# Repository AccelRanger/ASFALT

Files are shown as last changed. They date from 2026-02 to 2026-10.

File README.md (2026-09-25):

# ASFALT
**Accel Systems Line Following Robot**

A high-resolution line follower or edge follower calibrated for both usecases (TRD < for edge following, normal for line following) built on an Arduino Nano (ATmega328P), featuring a 16-sensor U-shaped IR array, custom KiCad PCBs, 3D-printed chassis parts, and a PID/proportional control algorithm with priority-based corner handling.

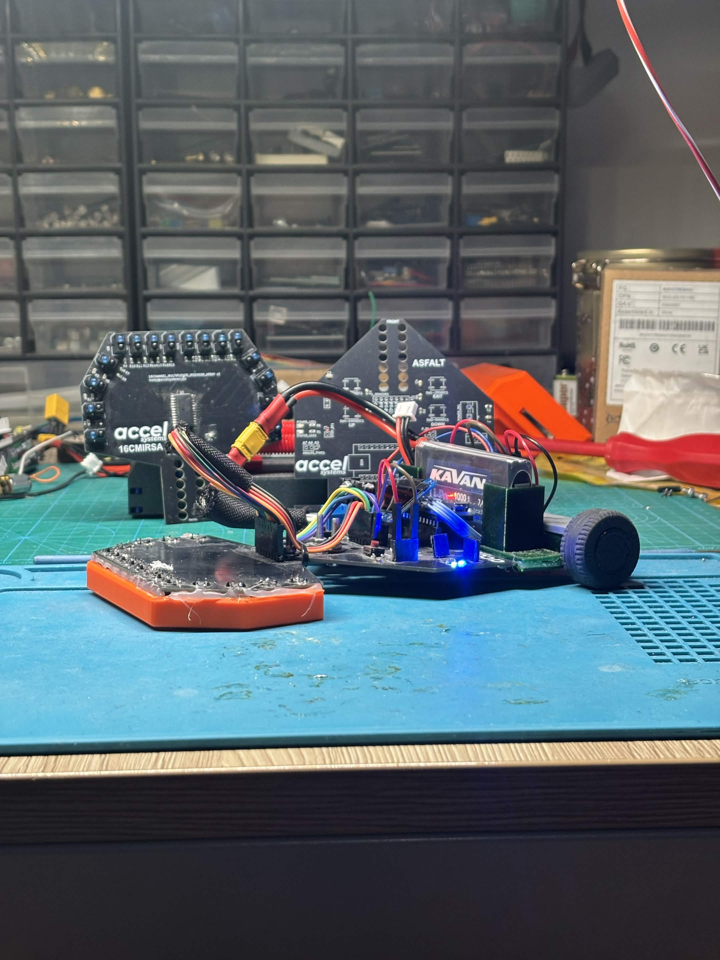
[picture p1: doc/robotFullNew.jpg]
Robot view Robot View


## License

This project is open source. Hardware designs, firmware, and mechanical files are provided as-is for personal and educational use.

---

*ASFALT — Accel Systems Line Following Robot*
*ASFALT-REV2 > Updated version single PCB, This repo has support till 1/10/2026

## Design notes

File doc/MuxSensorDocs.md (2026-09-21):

# MuxSensor

Custom Library for reading sensor inputs from 16CMIRSA

---

## Table of contents

- [Overview](#overview)
- [Constants](#constants)
- [Enums](#enums)
- [Constructor](#constructor)
- [API reference](#api-reference)
- [Calibration details](#calibration-details)
- [Digital thresholding](#digital-thresholding)
- [Channel select table](#channel-select-table)
- [Example sketch](#example-sketch)
- [Debug snippet](#debug-snippet)
- [Notes and caveats](#notes-and-caveats)

---

## Overview

`MuxSensor` controls a 16-to-1 analog multiplexer using four digital select lines (S0–S3) and one analog input (COM). It reads each of the 16 channels in sequence, runs a live calibration pass to record each sensor's min/max ADC extremes, and converts raw 10-bit ADC values to digital 0/1 signals using per-channel hysteresis windows.

Designed for **line-following robots** where a bank of IR sensors (e.g. TCRT5000) feeds a single ADC pin through a mux.

---

## Constants

| Macro | Value | Description |
|---|---|---|
| `MUX_NUM_CHANNELS` | `16` | Total channels on the multiplexer. |
| `MUX_CALIB_MARGIN` | `30` | ±ADC counts around each calibrated extreme forming the hysteresis window. Reduces noise-induced toggling. |
| `MUX_SETTLE_US` | `200` | Microseconds to wait after switching the mux channel before sampling. Allows the analog signal to settle. |

---

## Enums

### `MuxPolarity`

Describes how the sensor's ADC output maps to surface colour.

| Value | Description |
|---|---|
| `POLARITY_DARK_LOW` | Black surface → low ADC reading. Typical for TCRT5000 and most reflective IR sensors. **Default.** |
| `POLARITY_DARK_HIGH` | Black surface → high ADC reading. Use when your sensor circuit is inverted. |

---

## Constructor

```cpp
MuxSensor(uint8_t pinS0, uint8_t pinS1, uint8_t pinS2, uint8_t pinS3,
          uint8_t pinCOM,
          MuxPolarity polarity = POLARITY_DARK_LOW);
```

Creates a `MuxSensor` instance. Does **not** configure any pins — call `begin()` after construction.

| Parameter | Type | Description |
|---|---|---|
| `pinS0`–`pinS3` | `uint8_t` | Digital output pins connected to the mux select lines S0, S1, S2, S3. |
| `pinCOM` | `uint8_t` | Analog input pin connected to the mux common output (Z pin). |
| `polarity` | `MuxPolarity` | Optional. Sensor polarity. Defaults to `POLARITY_DARK_LOW`. |

All calibration arrays are initialised to `_calMin = 0`, `_calMax = 1023`, and `_calibrated = false`.

---

## API reference

### `begin()`

```cpp
void begin();
```

Sets S0–S3 as `OUTPUT` and selects channel 0. Call once in `setup()`.

> **Note:** Does not call `pinMode` on the COM pin. Make sure the COM pin is not configured as a digital output elsewhere in your sketch.

---

### `calibrate()`

```cpp
bool calibrate(uint32_t durationMs = 12000UL);
```

Sweeps all 16 channels continuously for `durationMs` milliseconds, recording the minimum and maximum ADC value seen on each channel. Move the sensor array over both black and white surfaces during this window.

| Parameter | Type | Description |
|---|---|---|
| `durationMs` | `uint32_t` | Calibration window in milliseconds. Default `12000` ms. |

**Returns** `true` if every channel has sufficient contrast — i.e. `calMin[i] + MUX_CALIB_MARGIN < calMax[i] - MUX_CALIB_MARGIN`. Returns `false` if any channel's range is too narrow, but still sets `_calibrated = true` so subsequent reads can proceed.

> **Warning:** This call **blocks the main loop** for the full duration. Use a non-blocking state machine if that is a concern.

---

### `isCalibrated()`

```cpp
bool isCalibrated() const;
```

Returns `true` after a successful `calibrate()` call, regardless of whether contrast was adequate on all channels.

---

### `getRawAnalogValues()`

```cpp
void getRawAnalogValues(uint16_t out[MUX_NUM_CHANNELS]);
```

Reads all 16 channels in order (ch0 → ch15) and writes the raw 10-bit ADC value (0–1023) into `out`. Does not require prior calibration.

| Parameter | Type | Description |
|---|---|---|
| `out` | `uint16_t[16]` | Caller-allocated array of 16 elements. Filled in channel order. |

---

### `getDigital()`

```cpp
bool getDigital(uint8_t out[MUX_NUM_CHANNELS]);
```

Reads all channels, applies the calibrated hysteresis windows, and writes a digital `0` or `1` per channel into `out`.

| Parameter | Type | Description |
|---|---|---|
| `out` | `uint8_t[16]` | Caller-allocated array. Each element is `0` (white / no surface) or `1` (black / surface detected), depending on polarity. |

**Returns** `false` immediately — leaving `out` unchanged — if `_calibrated` is `false`. Returns `true` on success.

If the current reading falls outside both the black and white zones, the previous digital value for that channel is retained (`_lastDigital[ch]`). This prevents glitching in mid-transition regions.

---

### `getCalibMin()`

```cpp
uint16_t getCalibMin(uint8_t ch) const;
```

Returns the minimum ADC value recorded for channel `ch` during the last calibration. Returns `0` for out-of-range channel indices.

---

### `getCalibMax()`

```cpp
uint16_t getCalibMax(uint8_t ch) const;
```

Returns the maximum ADC value recorded for channel `ch` during the last calibration. Returns `0` for out-of-range channel indices.

---

### `getThreshold()`

```cpp
uint16_t getThreshold(uint8_t ch) const;
```

Returns the midpoint `(calMin[ch] + calMax[ch]) / 2` for channel `ch`. Useful as a simple fixed threshold for debugging. Returns `0` for out-of-range channel indices.

---

## Calibration details

During `calibrate()`, the library:

1. Resets `_calMin[i]` to `1023` and `_calMax[i]` to `0` for all channels.
2. Polls all 16 channels in a tight loop (with 1 ms delay per sweep) until the deadline is reached.
3. After the sweep, checks whether each channel has enough contrast: `_calMin[i] + MUX_CALIB_MARGIN < _calMax[i] - MUX_CALIB_MARGIN`.
4. Sets `_calibrated = true` unconditionally and returns the contrast check result.

For reliable calibration, ensure the sensor passes over a clear black surface **and** a clear white surface during the calibration window.

---

## Digital thresholding

`getDigital()` defines two zones per channel based on calibrated extremes and `MUX_CALIB_MARGIN`:

```
blackLo = calMin[ch] - MUX_CALIB_MARGIN   (clamped to 0)
blackHi = calMin[ch] + MUX_CALIB_MARGIN

whiteLo = calMax[ch] - MUX_CALIB_MARGIN   (clamped to 0)
whiteHi = calMax[ch] + MUX_CALIB_MARGIN
```

The mapping of zones to digital output depends on polarity:

| Zone | `POLARITY_DARK_LOW` output | `POLARITY_DARK_HIGH` output |
|---|---|---|
| Reading in black zone | `1` | `0` |
| Reading in white zone | `0` | `1` |
| Reading in neither zone | retain previous value | retain previous value |

---

## Channel select table

The CD74HC4067 select lines S3, S2, S1, S0 address channels 0–15 as follows:

| Channel | S3 | S2 | S1 | S0 |
|---|---|---|---|---|
| 0  | 0 | 0 | 0 | 0 |
| 1  | 0 | 0 | 0 | 1 |
| 2  | 0 | 0 | 1 | 0 |
| 3  | 0 | 0 | 1 | 1 |
| 4  | 0 | 1 | 0 | 0 |
| 5  | 0 | 1 | 0 | 1 |
| 6  | 0 | 1 | 1 | 0 |
| 7  | 0 | 1 | 1 | 1 |
| 8  | 1 | 0 | 0 | 0 |
| 9  | 1 | 0 | 0 | 1 |
| 10 | 1 | 0 | 1 | 0 |
| 11 | 1 | 0 | 1 | 1 |
| 12 | 1 | 1 | 0 | 0 |
| 13 | 1 | 1 | 0 | 1 |
| 14 | 1 | 1 | 1 | 0 |
| 15 | 1 | 1 | 1 | 1 |

---

## Example sketch

```cpp
#include "MuxSensor.h"

// S0=4, S1=5, S2=6, S3=7, COM=A0
MuxSensor mux(4, 5, 6, 7, A0, POLARITY_DARK_LOW);

void setup() {
  Serial.begin(115200);
  mux.begin();

  Serial.println("Calibrating — move over black and white...");
  bool ok = mux.calibrate(5000);  // 5-second window
  Serial.println(ok ? "Calibrated OK" : "Low contrast on some channels");
}

void loop() {
  uint8_t bits[MUX_NUM_CHANNELS];
  if (mux.getDigital(bits)) {
    for (uint8_t i = 0; i < MUX_NUM_CHANNELS; i++) {
      Serial.print(bits[i]);
    }
    Serial.println();
  }
  delay(20);
}
```

---

## Debug snippet

Print calibration data for every channel after `calibrate()`:

```cpp
for (uint8_t i = 0; i < MUX_NUM_CHANNELS; i++) {
  Serial.print("ch");    Serial.print(i);
  Serial.print("  min="); Serial.print(mux.getCalibMin(i));
  Serial.print("  max="); Serial.print(mux.getCalibMax(i));
  Serial.print("  thr="); Serial.println(mux.getThreshold(i));
}
```

---

## Notes and caveats

- `calibrate()` always sets `_calibrated = true` even when it returns `false` (poor contrast). Reads via `getDigital()` will proceed — results may be unreliable on affected channels.
- `getThreshold()` is declared in the header but may not be present in all versions of the `.cpp`. Verify it is implemented before use.
- `MUX_SETTLE_US` (200 µs) is conservative. On fast MCUs you may be able to reduce it if your mux and sensor settle faster, saving time during full sweeps.
- Total scan time per full `getDigital()` call is approximately `16 × (MUX_SETTLE_US + analogRead time)` — roughly 3–5 ms on a standard Arduino Uno at default ADC prescaler.

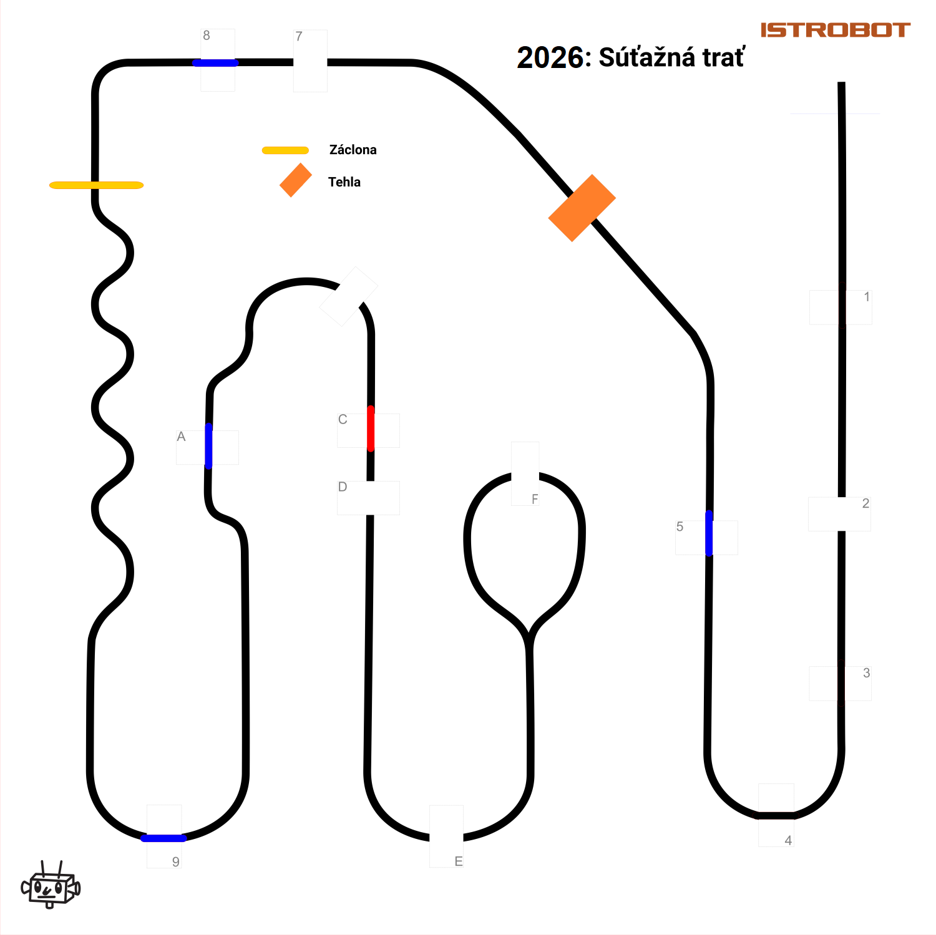
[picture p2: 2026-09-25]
src/img/LinefollowerTrack2026.png

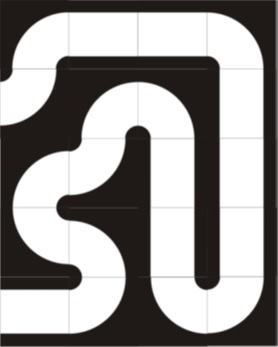
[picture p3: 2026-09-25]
src/img/edgeFollowingTrack.jpg

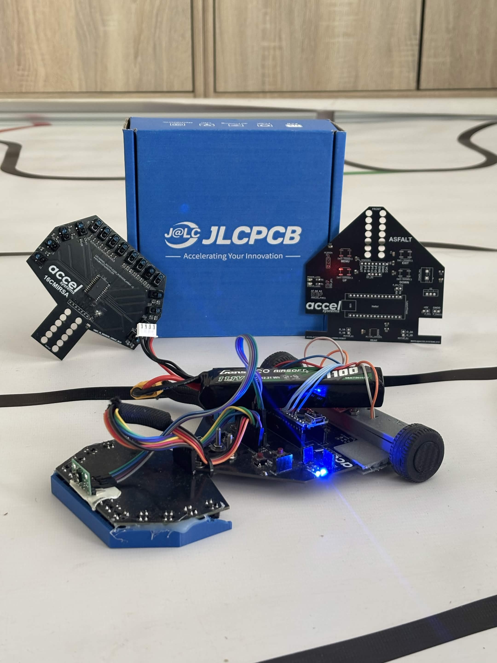
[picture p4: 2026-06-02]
doc/robotFull.jpg

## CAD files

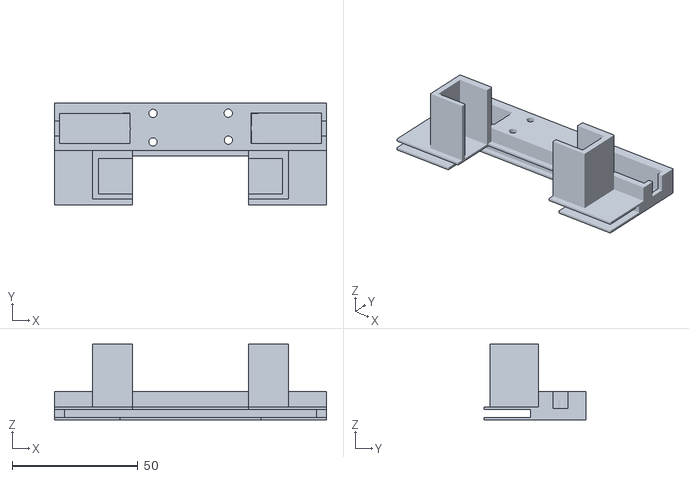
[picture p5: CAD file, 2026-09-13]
3dPrint/motorMount/v3/ASLNF_MOTOR_HOLDER_MAIN.stl
108.0 x 40.6 x 30.0

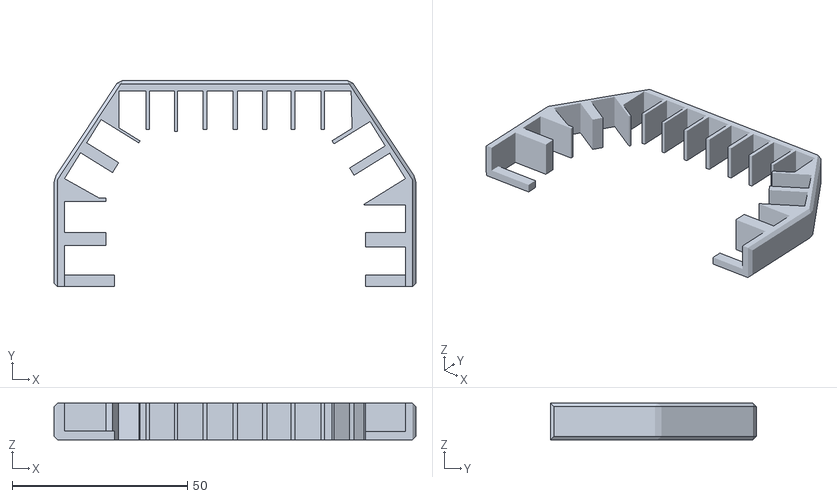
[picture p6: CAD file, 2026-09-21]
3dPrint/sensor/v2/LINE_SENSOR_TRCT.stl
103.2 x 58.8 x 10.5

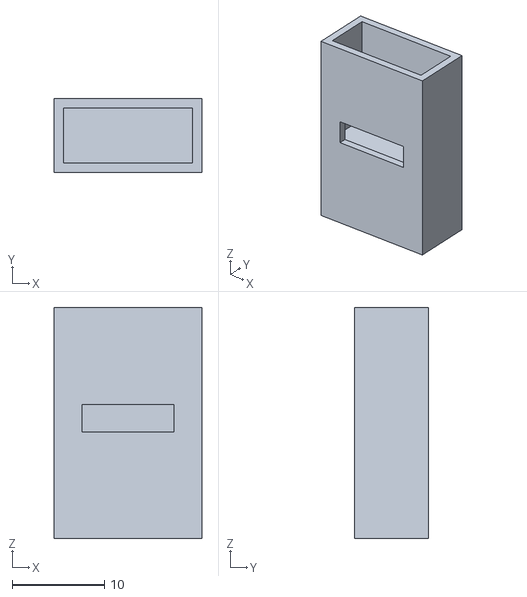
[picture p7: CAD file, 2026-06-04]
3dPrint/stopButton/StopButtonHolder.stl
16.0 x 8.00 x 25.0

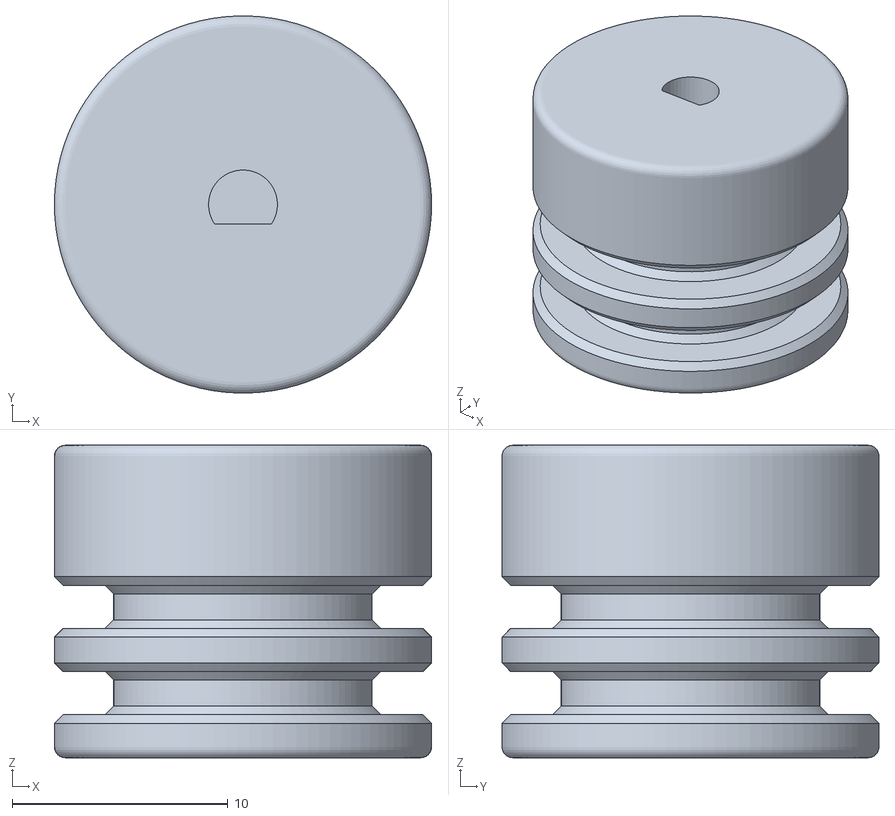
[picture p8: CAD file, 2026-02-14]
3dPrint/wheels/LEGO_30x04TIRE_TO_DSHAFT.stl
17.5 x 17.5 x 14.5

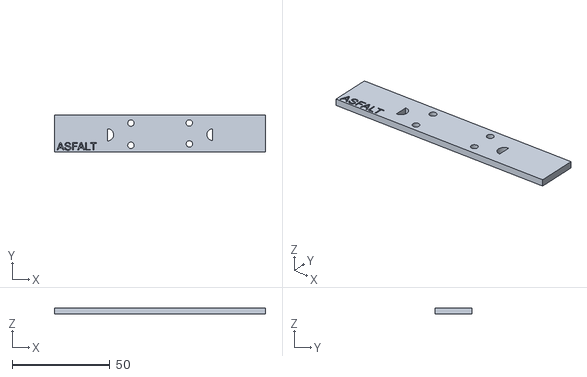
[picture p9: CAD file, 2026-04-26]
3dPrint/motorMount/v3/ASLNF_MOTOR_HOLDER_TOP.stl
108.0 x 19.0 x 3.00

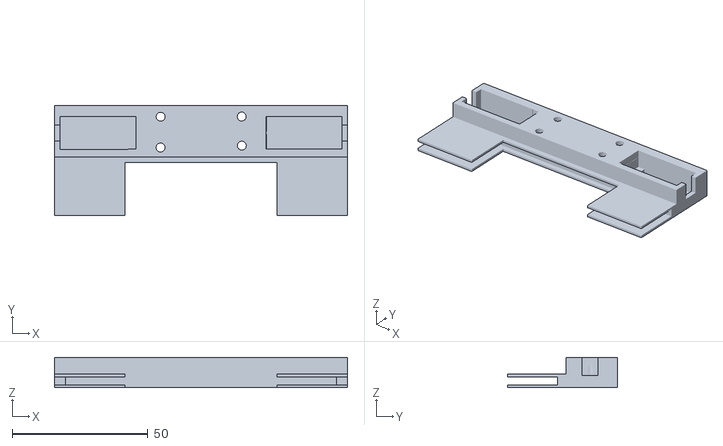
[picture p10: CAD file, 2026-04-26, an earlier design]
3dPrint/motorMount/v2/ASLNF_MOTOR_HOLDER_MAIN.stl
108.0 x 40.6 x 11.1

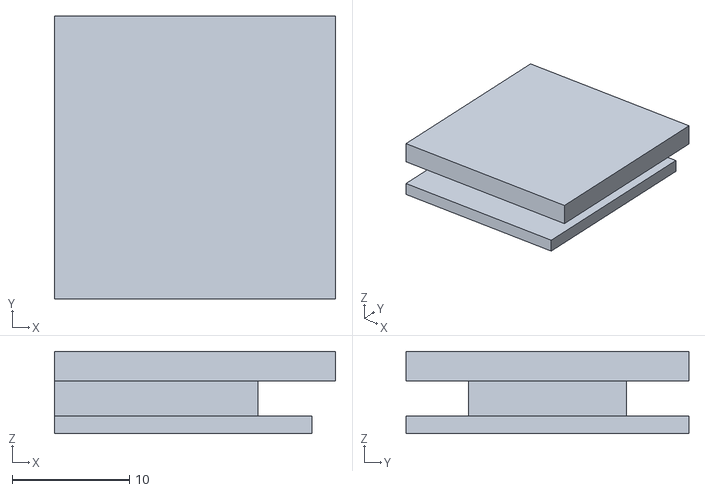
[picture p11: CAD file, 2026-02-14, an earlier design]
3dPrint/motorMount/v1/ASFALT_LINE_FOLLOWER_MOTOR_MOUNT.stl
24.0 x 24.2 x 7.00

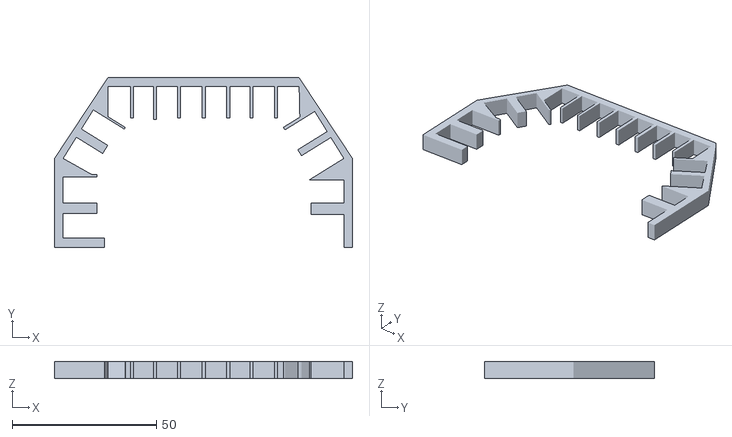
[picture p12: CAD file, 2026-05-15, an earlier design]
3dPrint/sensor/v1/LINE_SENSOR_TRCT.stl
103.2 x 58.8 x 6.00

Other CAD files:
3dPrint/motorMount/v1/ASFALT_LINE_FOLLOWER_MOTOR_MOUNT_V0.f3d

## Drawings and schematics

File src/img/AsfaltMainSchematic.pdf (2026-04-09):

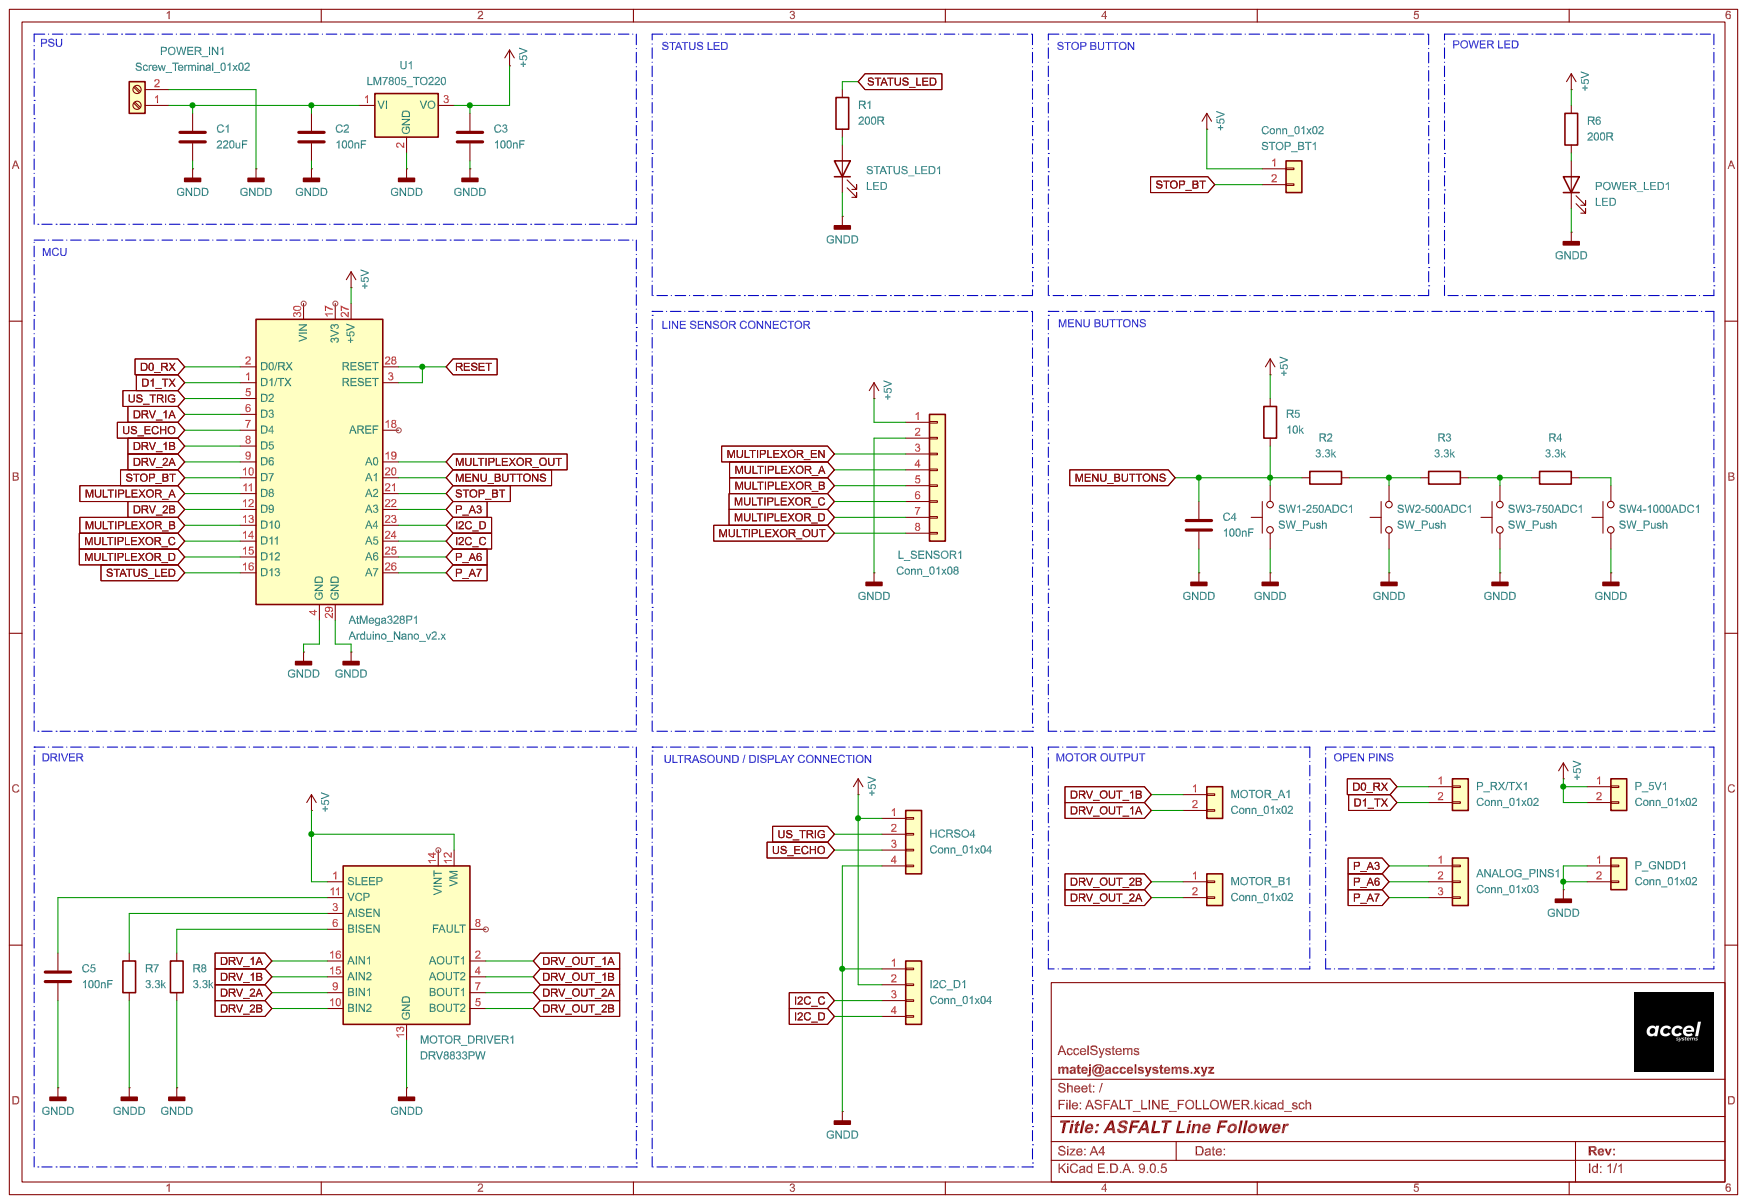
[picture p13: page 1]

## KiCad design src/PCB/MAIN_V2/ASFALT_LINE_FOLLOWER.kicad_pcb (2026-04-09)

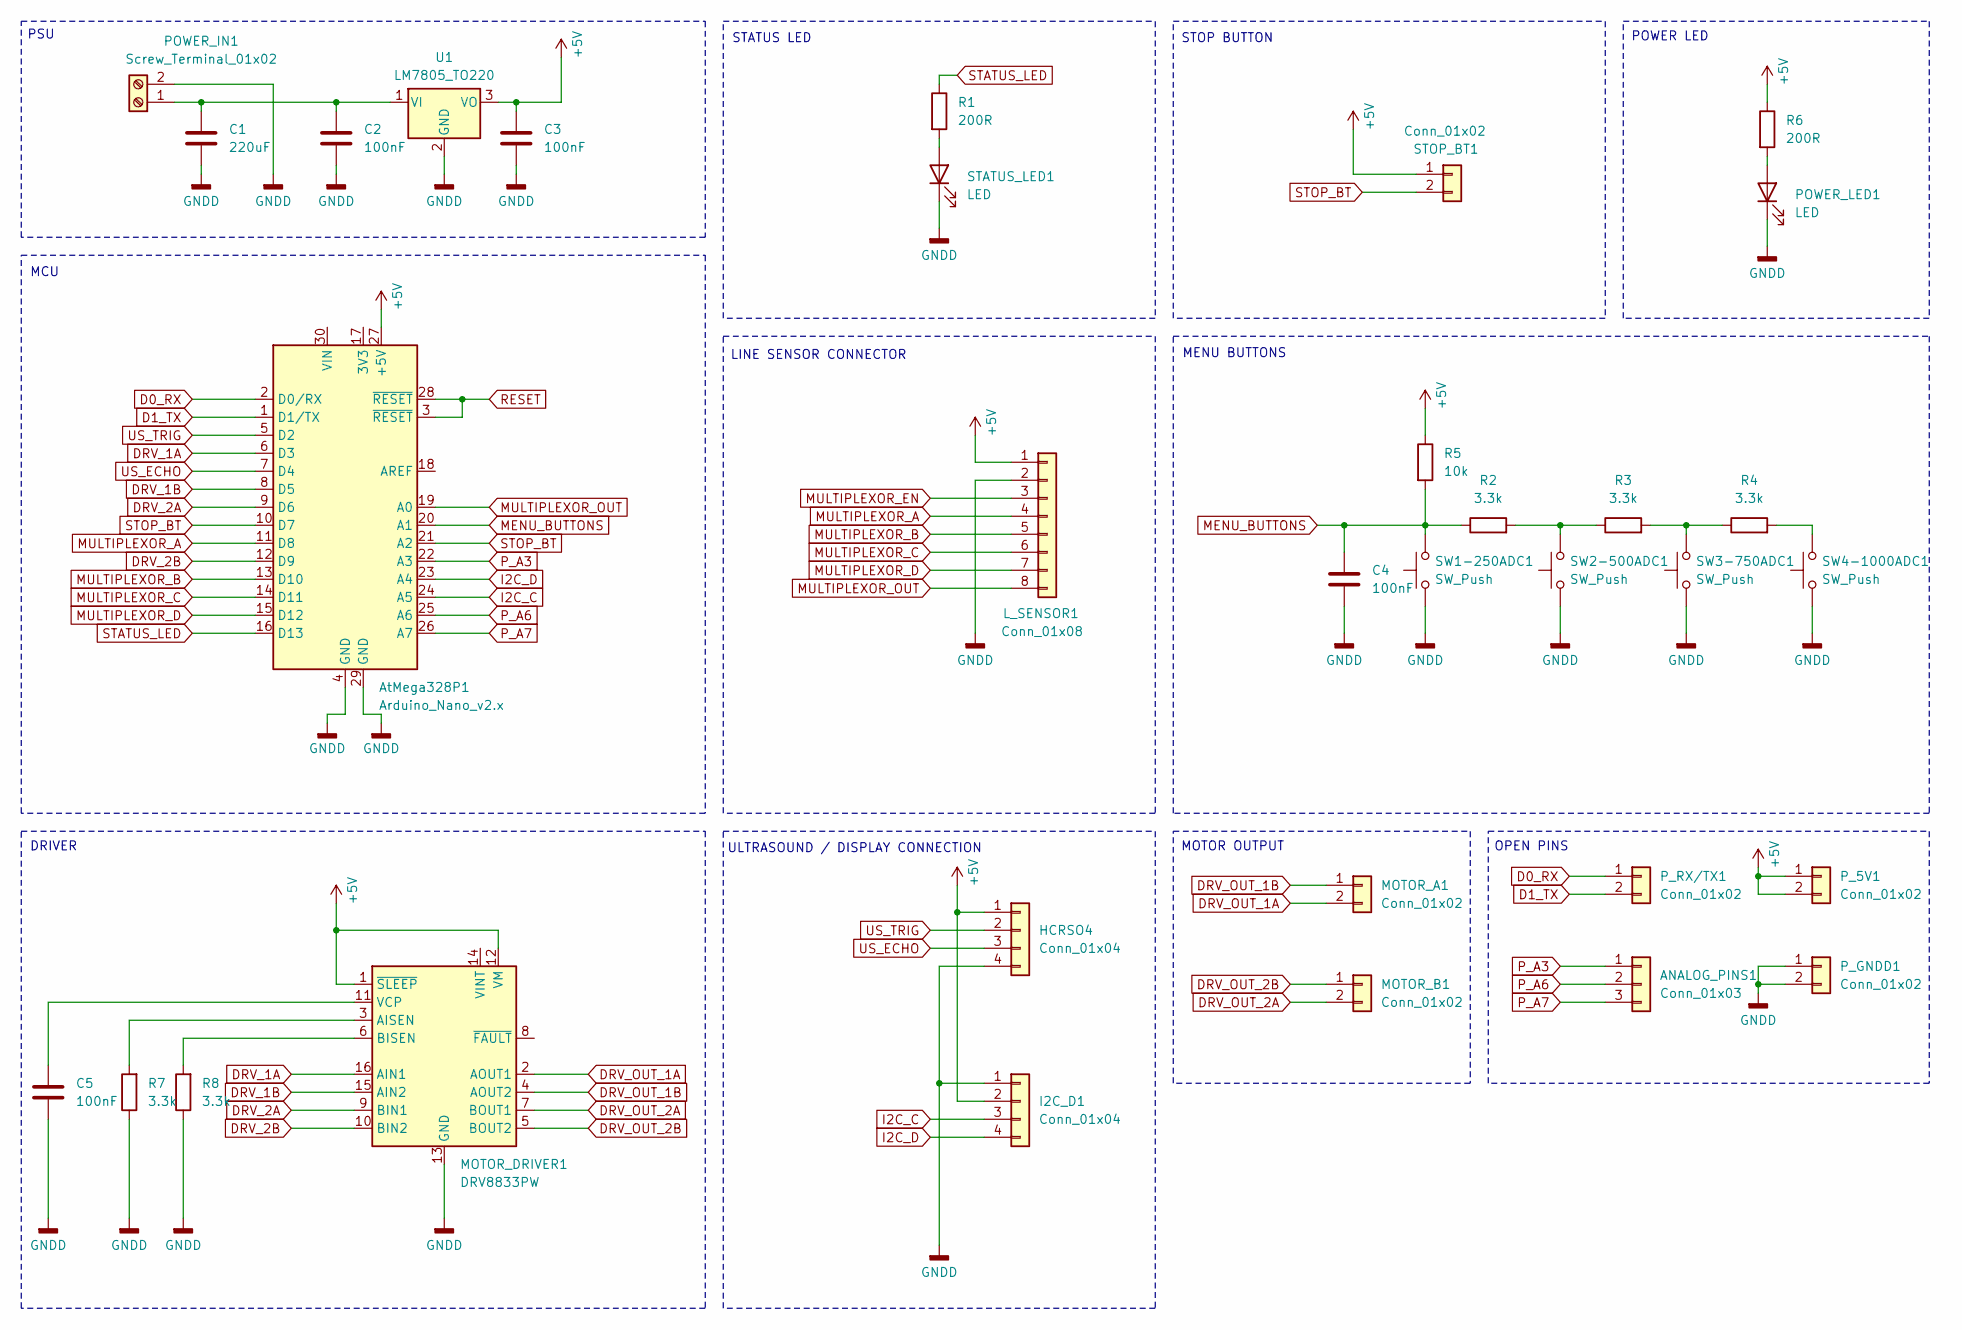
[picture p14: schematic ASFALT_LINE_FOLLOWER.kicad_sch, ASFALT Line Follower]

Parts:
ANALOG_PINS1: Conn_01x03; PinHeader_1x03_P2.54mm_Vertical
AtMega328P1: Arduino_Nano_v2.x; Arduino_Nano
C1: 220uF; C_0805_2012Metric_Pad1.18x1.45mm_HandSolder
C2, C3, C4, C5: 100nF; C_0805_2012Metric_Pad1.18x1.45mm_HandSolder
HCRSO4: Conn_01x04; PinHeader_1x04_P2.54mm_Vertical
I2C_D1: Conn_01x04; PinHeader_1x04_P2.54mm_Vertical
L_SENSOR1: Conn_01x08; PinHeader_1x08_P2.54mm_Vertical
MOTOR_A1: Conn_01x02; PinHeader_1x02_P2.54mm_Vertical
MOTOR_B1: Conn_01x02; PinHeader_1x02_P2.54mm_Vertical
MOTOR_DRIVER1: DRV8833PW; TSSOP-16_4.4x5mm_P0.65mm
POWER_IN1: Screw_Terminal_01x02; TerminalBlock_MaiXu_MX126-5.0-02P_1x02_P5.00mm
POWER_LED1: LED; LED_0805_2012Metric_Pad1.15x1.40mm_HandSolder
P_5V1: Conn_01x02; PinHeader_1x02_P2.54mm_Vertical
P_GNDD1: Conn_01x02; PinHeader_1x02_P2.54mm_Vertical
P_RX/TX1: Conn_01x02; PinHeader_1x02_P2.54mm_Vertical
R1, R6: 200R; R_0805_2012Metric_Pad1.20x1.40mm_HandSolder
R2, R3, R4, R7, R8: 3.3k; R_0805_2012Metric_Pad1.20x1.40mm_HandSolder
R5: 10k; R_0805_2012Metric_Pad1.20x1.40mm_HandSolder
STATUS_LED1: LED; LED_0805_2012Metric_Pad1.15x1.40mm_HandSolder
STOP_BT1: Conn_01x02; PinHeader_1x02_P2.54mm_Vertical
SW1-250ADC1, SW2-500ADC1, SW3-750ADC1, SW4-1000ADC1: SW_Push; SW_Push_1P1T_NO_CK_KSC6xxJ
U1: LM7805_TO220; TO-220-3_Vertical

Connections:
+5V: AtMega328P1.27 (+5V), C3.1, HCRSO4.1, I2C_D1.2, L_SENSOR1.1, MOTOR_DRIVER1.1 (~SLEEP), MOTOR_DRIVER1.12 (VM), P_5V1.1, P_5V1.2, R5.1, R6.1, STOP_BT1.1, U1.3 (VO)
D0_RX: AtMega328P1.2 (D0/RX), P_RX/TX1.1
D1_TX: AtMega328P1.1 (D1/TX), P_RX/TX1.2
DRV_1A: AtMega328P1.6 (D3), MOTOR_DRIVER1.16 (AIN1)
DRV_1B: AtMega328P1.8 (D5), MOTOR_DRIVER1.15 (AIN2)
DRV_2A: AtMega328P1.9 (D6), MOTOR_DRIVER1.9 (BIN1)
DRV_2B: AtMega328P1.12 (D9), MOTOR_DRIVER1.10 (BIN2)
DRV_OUT_1A: MOTOR_A1.2, MOTOR_DRIVER1.2 (AOUT1)
DRV_OUT_1B: MOTOR_A1.1, MOTOR_DRIVER1.4 (AOUT2)
DRV_OUT_2A: MOTOR_B1.2, MOTOR_DRIVER1.7 (BOUT1)
DRV_OUT_2B: MOTOR_B1.1, MOTOR_DRIVER1.5 (BOUT2)
GNDD: AtMega328P1.4 (GND), AtMega328P1.29 (GND), C1.2, C2.2, C3.2, C4.2, C5.2, HCRSO4.4, I2C_D1.1, L_SENSOR1.2, MOTOR_DRIVER1.13 (GND), POWER_IN1.2, POWER_LED1.1 (K), P_GNDD1.1, P_GNDD1.2, R7.1, R8.1, STATUS_LED1.1 (K), SW1-250ADC1.1, SW2-500ADC1.1, SW3-750ADC1.1, SW4-1000ADC1.1, U1.2 (GND)
I2C_C: AtMega328P1.24 (A5), I2C_D1.3
I2C_D: AtMega328P1.23 (A4), I2C_D1.4
MENU_BUTTONS: AtMega328P1.20 (A1), C4.1, R2.1, R5.2, SW1-250ADC1.2
MULTIPLEXOR_A: AtMega328P1.11 (D8), L_SENSOR1.4
MULTIPLEXOR_B: AtMega328P1.13 (D10), L_SENSOR1.5
MULTIPLEXOR_C: AtMega328P1.14 (D11), L_SENSOR1.6
MULTIPLEXOR_D: AtMega328P1.15 (D12), L_SENSOR1.7
MULTIPLEXOR_EN: L_SENSOR1.3
MULTIPLEXOR_OUT: AtMega328P1.19 (A0), L_SENSOR1.8
unnamed: MOTOR_DRIVER1.3 (AISEN), R7.2
unnamed: MOTOR_DRIVER1.6 (BISEN), R8.2
unnamed: C5.1, MOTOR_DRIVER1.11 (VCP)
unnamed: C1.1, C2.1, POWER_IN1.1, U1.1 (VI)
unnamed: POWER_LED1.2 (A), R6.2
unnamed: R2.2, R3.1, SW2-500ADC1.2
unnamed: R3.2, R4.1, SW3-750ADC1.2
unnamed: R4.2, SW4-1000ADC1.2
unnamed: R1.2, STATUS_LED1.2 (A)
P_A3: ANALOG_PINS1.1, AtMega328P1.22 (A3)
P_A6: ANALOG_PINS1.2, AtMega328P1.25 (A6)
P_A7: ANALOG_PINS1.3, AtMega328P1.26 (A7)
RESET: AtMega328P1.3 (~RESET), AtMega328P1.28 (~RESET)
STATUS_LED: AtMega328P1.16 (D13), R1.1
STOP_BT: AtMega328P1.10 (D7), AtMega328P1.21 (A2), STOP_BT1.2
US_ECHO: AtMega328P1.7 (D4), HCRSO4.3
US_TRIG: AtMega328P1.5 (D2), HCRSO4.2

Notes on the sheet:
MCU
MENU BUTTONS
OPEN PINS
PSU
ULTRASOUND / DISPLAY CONNECTION
POWER LED
LINE SENSOR CONNECTOR
DRIVER
STATUS LED
STOP BUTTON
MOTOR OUTPUT

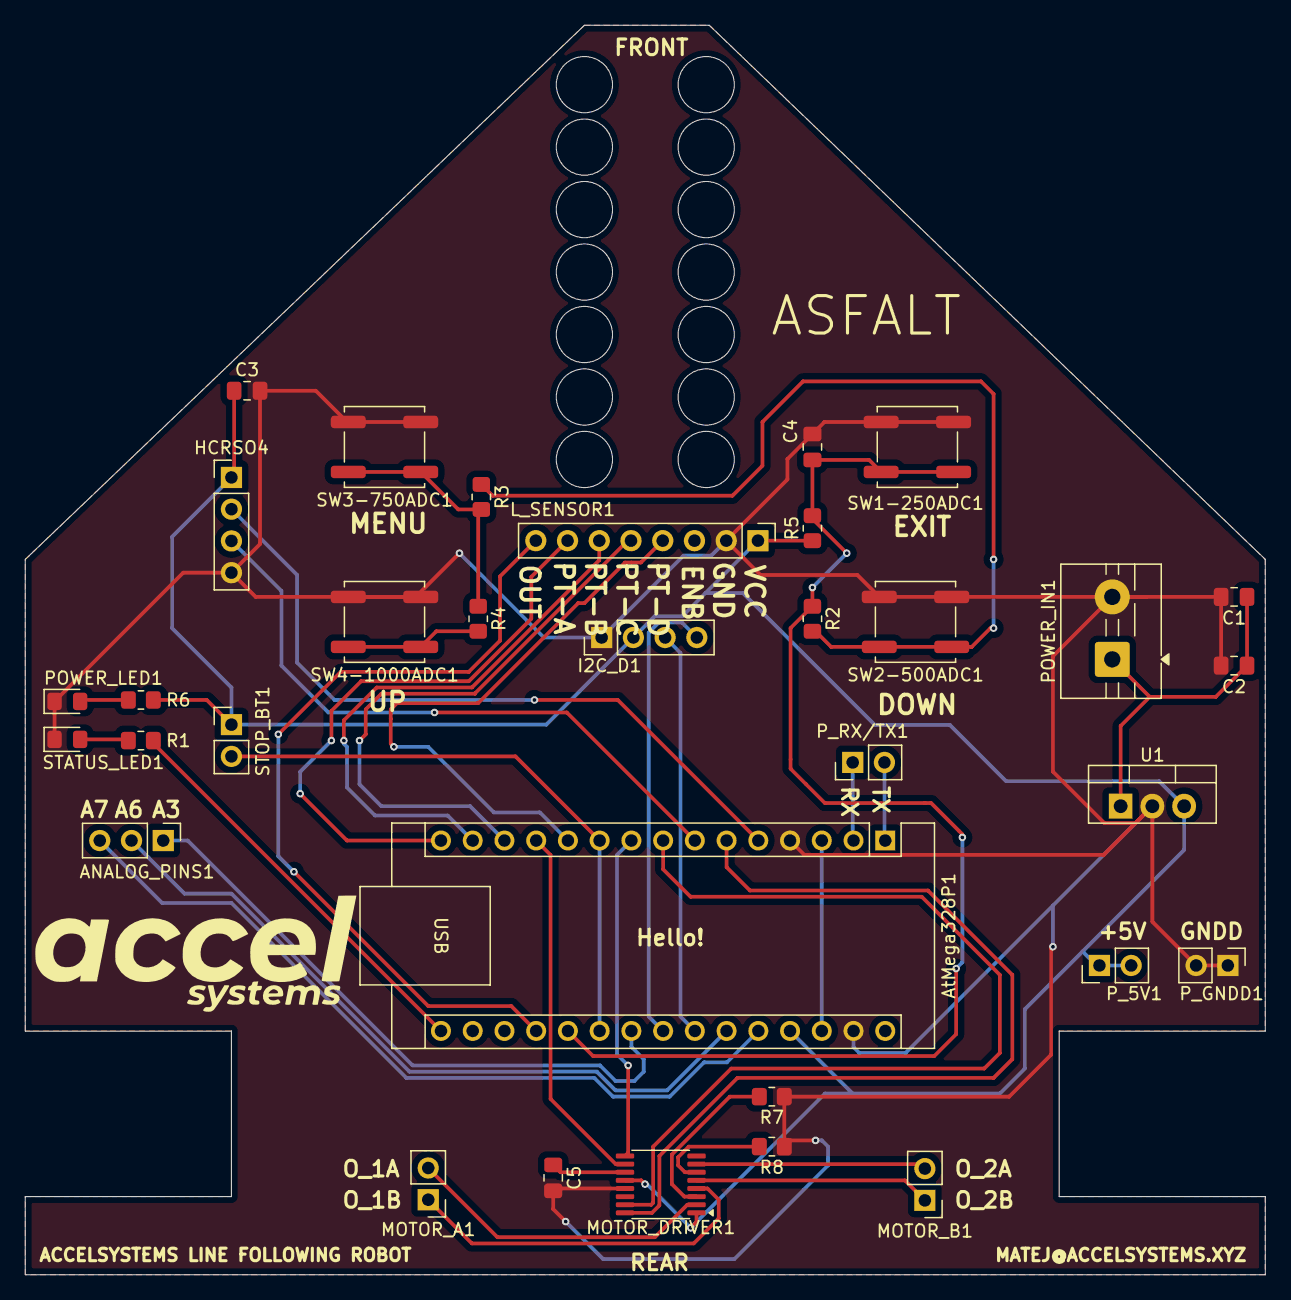
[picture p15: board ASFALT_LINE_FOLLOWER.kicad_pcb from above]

Board: 2 copper layers, 99.2 x 100.0 mm, 33 parts (0 on the bottom side), 37 nets.

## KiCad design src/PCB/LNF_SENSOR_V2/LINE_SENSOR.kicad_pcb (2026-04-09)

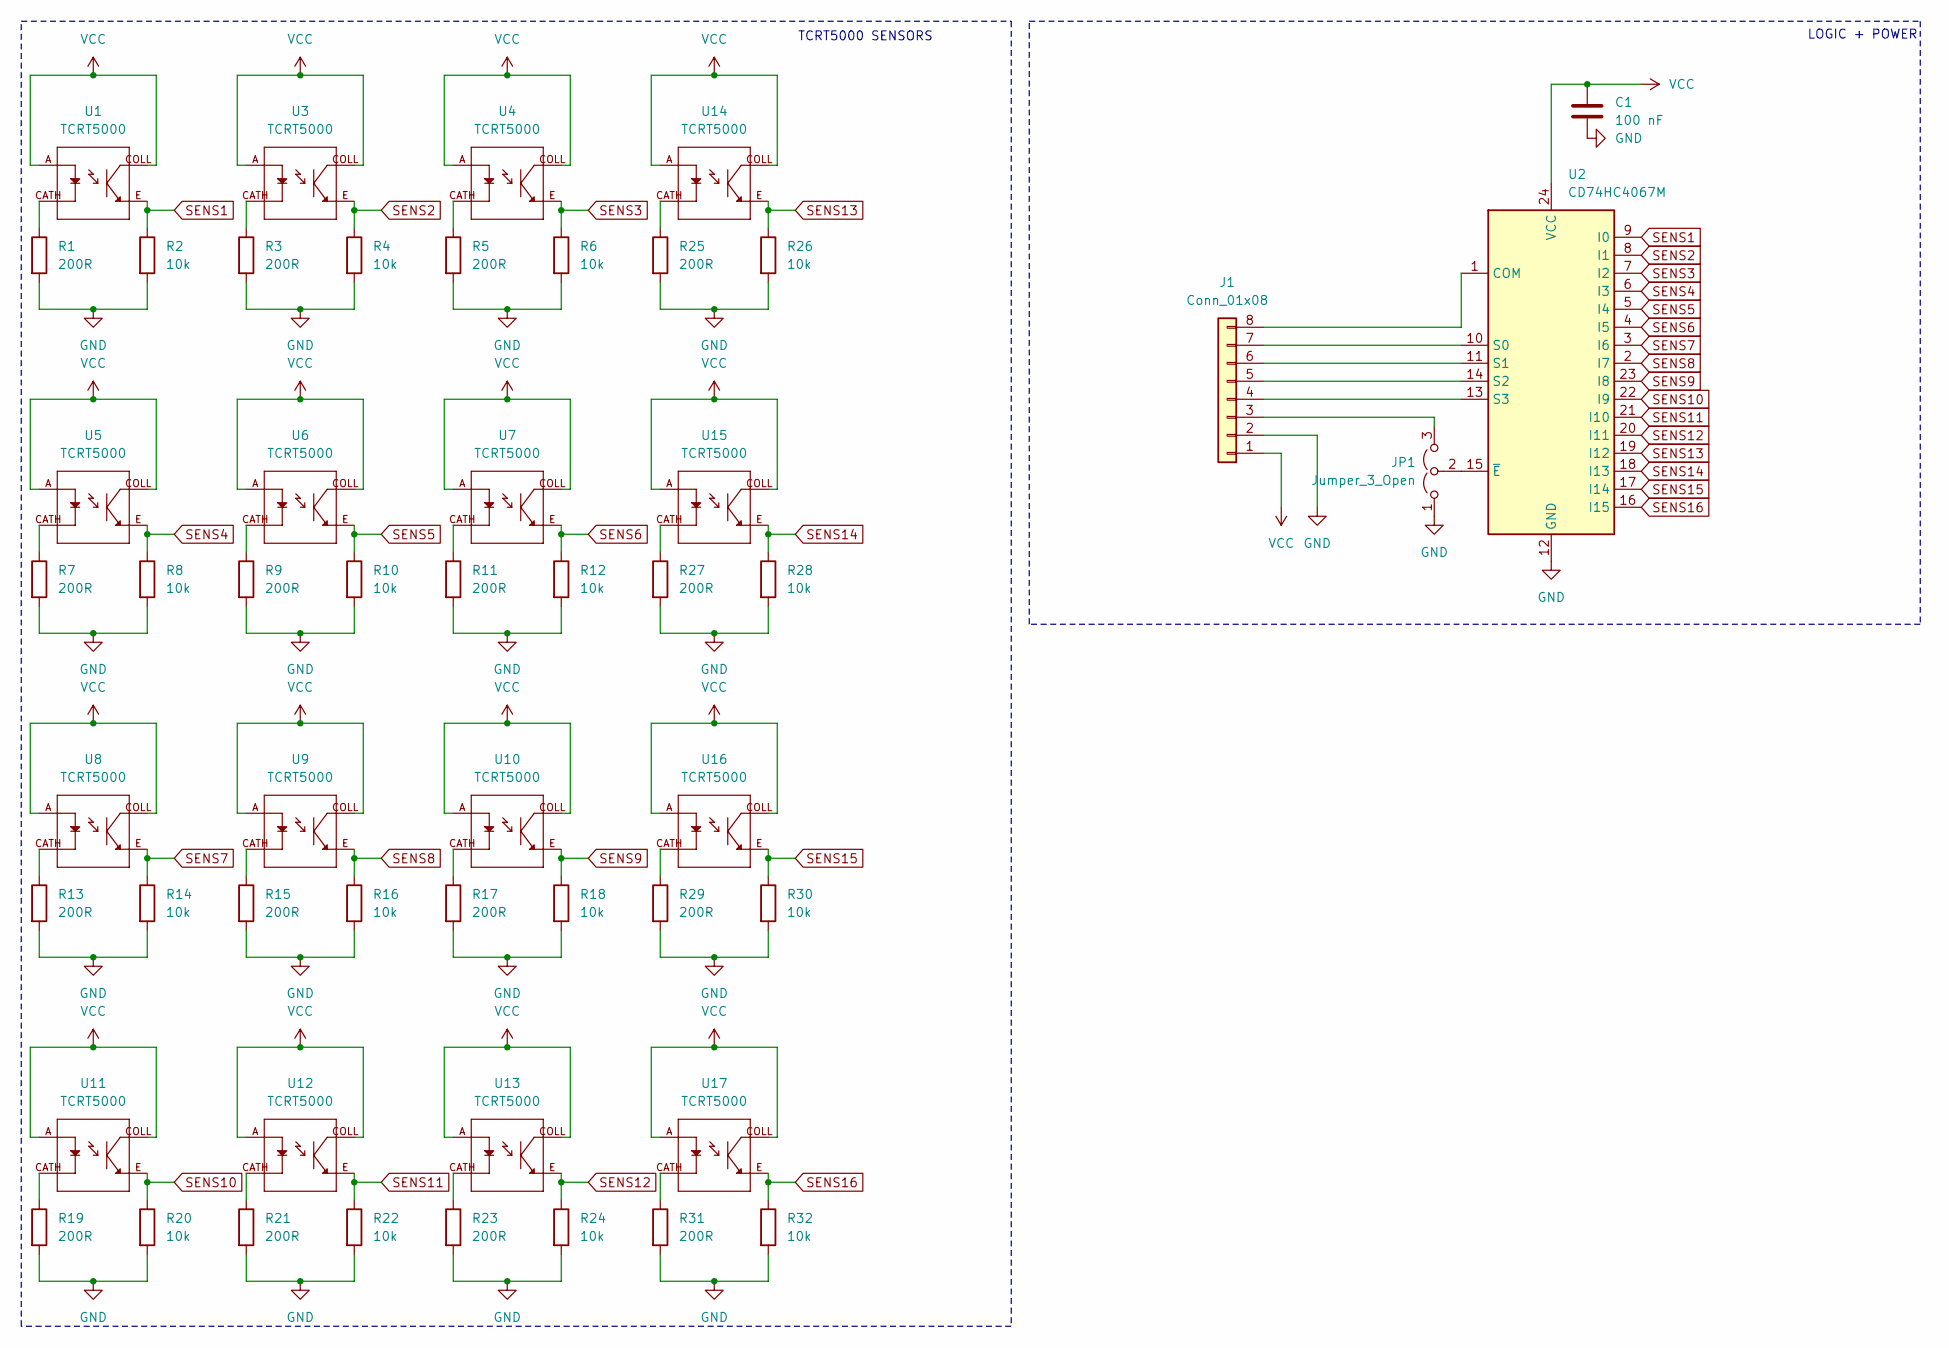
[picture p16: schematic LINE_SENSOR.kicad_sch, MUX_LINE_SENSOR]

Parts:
C1: 100 nF; C_0805_2012Metric
J1: Conn_01x08; PinHeader_1x08_P2.54mm_Vertical
JP1: Jumper_3_Open; SolderJumper-3_P1.3mm_Open_Pad1.0x1.5mm
R1, R3, R5, R7, R9, R11, R13, R15, R17, R19, R21, R23, R25, R27, R29, R31: 200R; R_0805_2012Metric
R2, R4, R6, R8, R10, R12, R14, R16, R18, R20, R22, R24, R26, R28, R30, R32: 10k; R_0805_2012Metric
U1, U3, U4, U5, U6, U7, U8, U9, U10, U11, U12, U13, U14, U15, U16, U17: TCRT5000; OPTO_TCRT5000; PARTREV 1.7
U2: CD74HC4067M; SOIC-24W_7.5x15.4mm_P1.27mm

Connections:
GND: C1.2, J1.2, JP1.1 (A), R1.2, R2.2, R3.2, R4.2, R5.2, R6.2, R7.2, R8.2, R9.2, R10.2, R11.2, R12.2, R13.2, R14.2, R15.2, R16.2, R17.2, R18.2, R19.2, R20.2, R21.2, R22.2, R23.2, R24.2, R25.2, R26.2, R27.2, R28.2, R29.2, R30.2, R31.2, R32.2, U2.12 (GND)
unnamed: J1.3, JP1.3 (B)
unnamed: J1.4, U2.13 (S3)
unnamed: J1.5, U2.14 (S2)
unnamed: J1.6, U2.11 (S1)
unnamed: J1.7, U2.10 (S0)
unnamed: J1.8, U2.1 (COM)
unnamed: JP1.2 (C), U2.15 (~E)
unnamed: R1.1, U1.CATH
unnamed: R3.1, U3.CATH
unnamed: R5.1, U4.CATH
unnamed: R7.1, U5.CATH
unnamed: R9.1, U6.CATH
unnamed: R11.1, U7.CATH
unnamed: R13.1, U8.CATH
unnamed: R15.1, U9.CATH
unnamed: R17.1, U10.CATH
unnamed: R19.1, U11.CATH
unnamed: R21.1, U12.CATH
unnamed: R23.1, U13.CATH
unnamed: R25.1, U14.CATH
unnamed: R27.1, U15.CATH
unnamed: R29.1, U16.CATH
unnamed: R31.1, U17.CATH
SENS1: R2.1, U1.E, U2.9 (I0)
SENS2: R4.1, U2.8 (I1), U3.E
SENS3: R6.1, U2.7 (I2), U4.E
SENS4: R8.1, U2.6 (I3), U5.E
SENS5: R10.1, U2.5 (I4), U6.E
SENS6: R12.1, U2.4 (I5), U7.E
SENS7: R14.1, U2.3 (I6), U8.E
SENS8: R16.1, U2.2 (I7), U9.E
SENS9: R18.1, U2.23 (I8), U10.E
SENS10: R20.1, U2.22 (I9), U11.E
SENS11: R22.1, U2.21 (I10), U12.E
SENS12: R24.1, U2.20 (I11), U13.E
SENS13: R26.1, U2.19 (I12), U14.E
SENS14: R28.1, U2.18 (I13), U15.E
SENS15: R30.1, U2.17 (I14), U16.E
SENS16: R32.1, U2.16 (I15), U17.E
VCC: C1.1, J1.1, U1.A, U1.COLL, U2.24 (VCC), U3.A, U3.COLL, U4.A, U4.COLL, U5.A, U5.COLL, U6.A, U6.COLL, U7.A, U7.COLL, U8.A, U8.COLL, U9.A, U9.COLL, U10.A, U10.COLL, U11.A, U11.COLL, U12.A, U12.COLL, U13.A, U13.COLL, U14.A, U14.COLL, U15.A, U15.COLL, U16.A, U16.COLL, U17.A, U17.COLL

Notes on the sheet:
TCRT5000 SENSORS
LOGIC + POWER

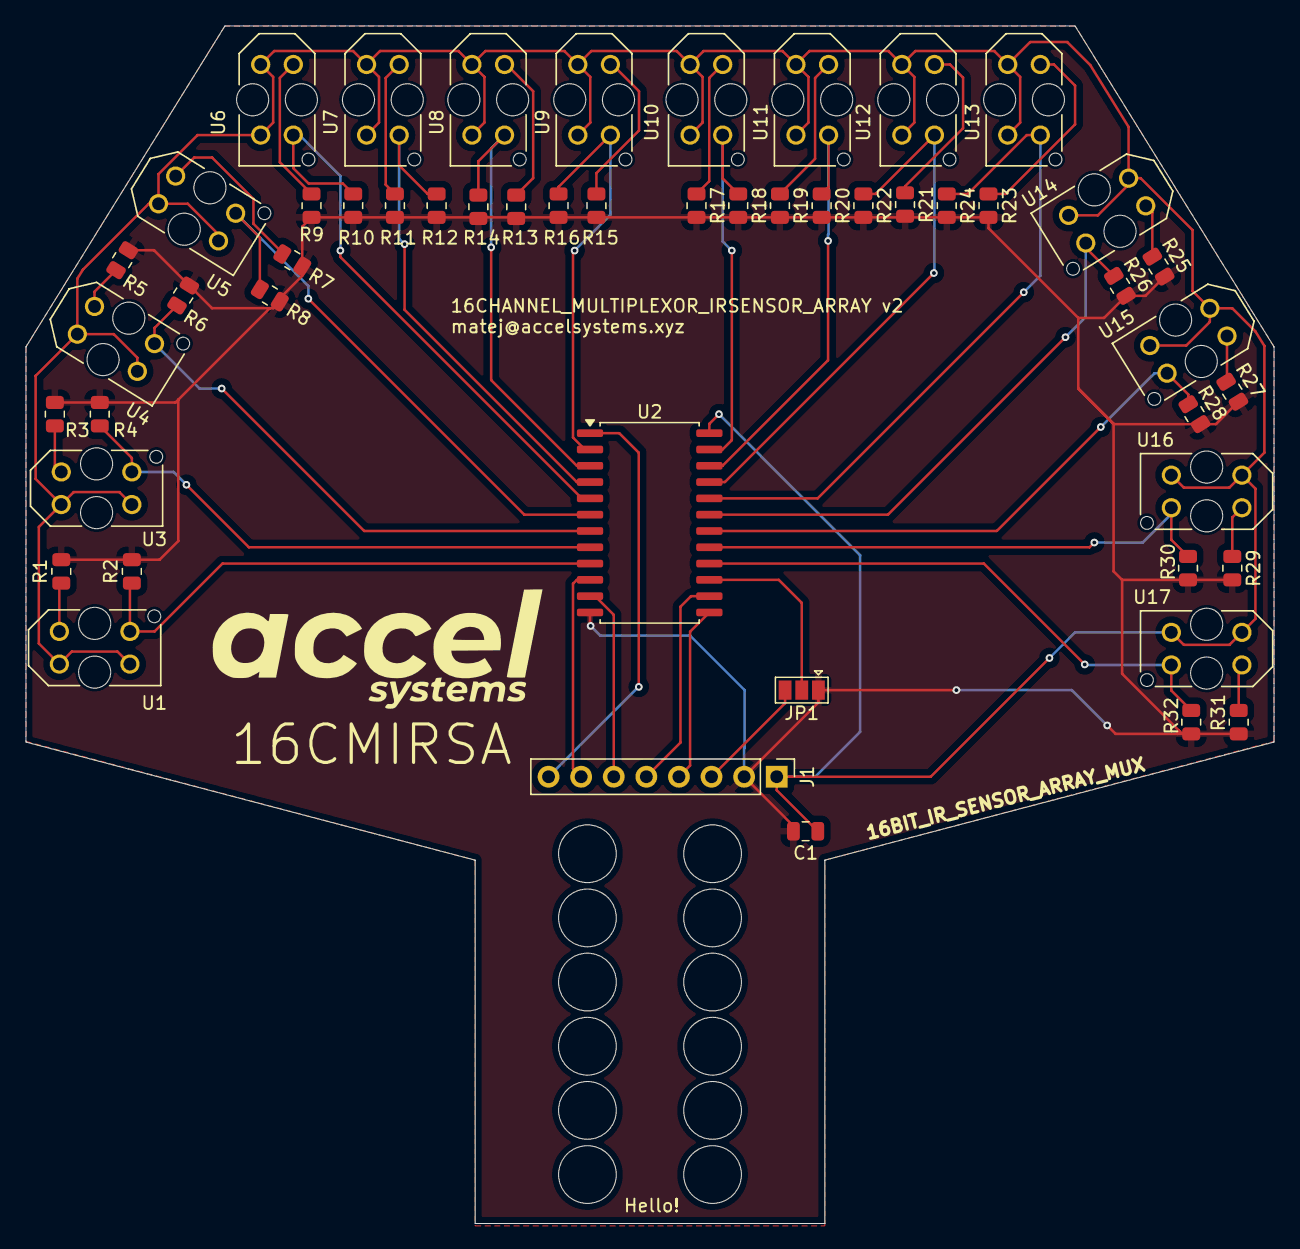
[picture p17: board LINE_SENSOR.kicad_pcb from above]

Board: 2 copper layers, 97.2 x 93.3 mm, 52 parts (0 on the bottom side), 41 nets.

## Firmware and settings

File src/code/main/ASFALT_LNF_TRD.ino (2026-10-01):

#include "MuxSensor.h"

void setMotors(int left, int right);
void stop();
int  findEdge();
void detectEdgeSide();
void setEdgeSide(bool left);
void handleSerial();
int  getAdaptiveSpeed(int error);
void recover();
void pidStep();
void setup();
void loop();

// ── line sensor pins ──────────────────────────────────
#define PIN_S0   12
#define PIN_S1   11
#define PIN_S2   10
#define PIN_S3    8
#define PIN_COM  A0

#define STOP_BT 7

MuxSensor sensor(PIN_S0, PIN_S1, PIN_S2, PIN_S3, PIN_COM, POLARITY_DARK_LOW);
uint8_t digital[MUX_NUM_CHANNELS];

// ── motor pins ────────────────────────────────────────
#define LEFT_A    6
#define LEFT_B    9
#define RIGHT_A   5
#define RIGHT_B   3

bool followLeftEdge = true;

#define DEFAULT_FOLLOW_LEFT_EDGE  true
#define AUTO_DETECT_SIDE          1     // 0 = always use the default above

#define N_SENS      16                  // array size
#define POS_MAX     ((N_SENS - 1) * 1000)   // 15000
#define EDGE_TARGET 8000                // where we want the boundary to sit
#define ERROR_MAX   8000

#define FOLLOW_SIDE       1     // 0 = follow LEFT edge, 1 = follow RIGHT edge
#define AUTO_DETECT_SIDE  0     // 0 = use FOLLOW_SIDE above, 1 = auto-detect at startup

#define DEFAULT_FOLLOW_LEFT_EDGE  (FOLLOW_SIDE == 0)

// 1.0 = no filtering, 0.2 = heavy. wobble fixing
#define EDGE_ALPHA  0.45f

float   edgeFilt  = (float)EDGE_TARGET;
int     lastEdge  = EDGE_TARGET;
uint8_t darkCount = 0;

// ── PID config ────────────────────────────────────────
int   baseSpeed          = 220;
float kp                 = 0.048f;
float ki                 = 0.0005f;
float kd                 = 0.9f;    // lowered: digital edge steps are 1000 counts
int   sharpTurnThreshold = 20;
int   minTurnSpeed       = 75;
float iClamp             = 800.0f;

int rightLossSpeed  = 200;    // reduced forward speed while searching
int rightLossTurn   = -120;    // how hard to bias right (bigger = tighter turn)

int leftLossSpeed  = 150;     // reduced forward speed while searching
int leftLossTurn   = 200;     // how hard to bias left (bigger = tighter turn)

// ── PID state ─────────────────────────────────────────
int   last_error = 0;
float integral   = 0.0f;

// ── Motor helpers ─────────────────────────────────────
void setMotors(int left, int right) {
  left  = constrain(left,  -255, 255);
  right = constrain(right, -255, 255);
  analogWrite(LEFT_A,  left  > 0 ?  left  : 0);
  analogWrite(LEFT_B,  left  < 0 ? -left  : 0);
  analogWrite(RIGHT_A, right > 0 ?  right : 0);
  analogWrite(RIGHT_B, right < 0 ? -right : 0);
}
void stop() { setMotors(0, 0); }

int findEdge() {
  sensor.getDigital(digital);

  darkCount = 0;
  for (uint8_t i = 0; i < N_SENS; i++) {
    if (digital[i]) darkCount++;
  }

  if (darkCount == 0 || darkCount == N_SENS) return -1;   // uniform, no boundary

  int  best     = -1;
  long bestDist = 0x7FFFFFFF;

  for (uint8_t i = 0; i + 1 < N_SENS; i++) {
    bool isEdge = followLeftEdge ? (!digital[i] &&  digital[i + 1])   // white → black
                                 : ( digital[i] && !digital[i + 1]);  // black → white
    if (!isEdge) continue;

    int  pos = (int)i * 1000 + 500;
    long d   = labs((long)pos - (long)lastEdge);
    if (d < bestDist) { bestDist = d; best = pos; }
  }
  return best;
}

void detectEdgeSide() {
  long rightWeight = 0;
  long totalDark   = 0;

  for (uint8_t s = 0; s < 10; s++) {
    sensor.getDigital(digital);
    for (uint8_t i = 0; i < N_SENS; i++) {
      if (digital[i]) {
        totalDark++;
        if (i >= N_SENS / 2) rightWeight++;
      }
    }
    delay(10);
  }

  if (totalDark == 0) {
    followLeftEdge = DEFAULT_FOLLOW_LEFT_EDGE;
    Serial.println("Auto-detect: no black seen, using default side.");
    return;
  }

  followLeftEdge = (rightWeight * 2 > totalDark);   // majority of dark on the right
  Serial.print("Auto-detect: black is on the ");
  Serial.print(followLeftEdge ? "RIGHT" : "LEFT");
  Serial.print(" -> following ");
  Serial.print(followLeftEdge ? "LEFT" : "RIGHT");
  Serial.println(" edge.");
}

// ── Switch sides cleanly (resets control state) ───────
void setEdgeSide(bool left) {
  followLeftEdge = left;
  lastEdge   = EDGE_TARGET;
  edgeFilt   = (float)EDGE_TARGET;
  last_error = 0;
  integral   = 0.0f;
  Serial.print("Now following the ");
  Serial.print(left ? "LEFT" : "RIGHT");
  Serial.println(" edge of the black area.");
}

// ── Serial commands: 'l' / 'r' to switch live ─────────
void handleSerial() {
  while (Serial.available()) {
    char c = Serial.read();
    if (c == 'l' || c == 'L') setEdgeSide(true);
    if (c == 'r' || c == 'R') setEdgeSide(false);
  }
}

// ── Adaptive speed ────────────────────────────────────
int getAdaptiveSpeed(int error) {
  int absError = abs(error);
  if (absError <= sharpTurnThreshold) return baseSpeed;
  float t = (float)(absError - sharpTurnThreshold) / (ERROR_MAX - sharpTurnThreshold);
  t = constrain(t, 0.0f, 1.0f);
  return (int)(baseSpeed - (baseSpeed - minTurnSpeed) * t);
}

// ── Recovery when the edge leaves the array ───────────
void recover() {
  if (!followLeftEdge) {
    setMotors(rightLossSpeed, rightLossTurn);
    return;
  }

  setMotors(leftLossSpeed - leftLossTurn, leftLossSpeed);
}

// ── PID step ──────────────────────────────────────────
void pidStep() {
  int e = findEdge();

  bool allWhite = (darkCount == 0);
  bool allBlack = (darkCount == N_SENS);

  if (allWhite) {
    Serial.println("Full white - line lost");
    recover();
    return;
  }

  if (e < 0) {          // all black, or no edge found
    recover();
    return;
  }

  lastEdge = e;
  edgeFilt += EDGE_ALPHA * ((float)e - edgeFilt);

  int error = (int)edgeFilt - EDGE_TARGET;

  if (!followLeftEdge) error = -error;

  if (abs(error) < abs(last_error)) {
    integral *= 0.85f;
  }

  integral += error;
  integral  = constrain(integral, -iClamp, iClamp);

  int correction = (int)(kp * error)
                 + (int)(ki * integral)
                 + (int)(kd * (error - last_error));

  int speed = getAdaptiveSpeed(error);
  setMotors(speed + correction, speed - correction);
  last_error = error;
}

// ── Setup ─────────────────────────────────────────────
void setup() {
  Serial.begin(9600);

  pinMode(LEFT_A,      OUTPUT);
  pinMode(LEFT_B,      OUTPUT);
  pinMode(RIGHT_A,     OUTPUT);
  pinMode(RIGHT_B,     OUTPUT);
  pinMode(LED_BUILTIN, OUTPUT);
  pinMode(STOP_BT,     INPUT_PULLUP);

  sensor.begin();
  stop();

  Serial.println("Calibrating...");
  digitalWrite(LED_BUILTIN, HIGH);
  bool ok = sensor.calibrate(12000UL);
  digitalWrite(LED_BUILTIN, LOW);
  Serial.println(ok ? "Calibration OK" : "Calibration low-contrast!");

  followLeftEdge = DEFAULT_FOLLOW_LEFT_EDGE;
#if AUTO_DETECT_SIDE
  // Place the robot straddling the edge before this runs.
  detectEdgeSide();
#endif

  lastEdge = EDGE_TARGET;
  edgeFilt = (float)EDGE_TARGET;

  Serial.println("Send 'l' or 'r' to switch edge side at any time.");
  delay(1000);
}

// ── Loop ──────────────────────────────────────────────
void loop() {
  handleSerial();

  if (digitalRead(STOP_BT) == LOW) {
    stop();
    Serial.println("pressed");
    while (true);
  }

  pidStep();
}

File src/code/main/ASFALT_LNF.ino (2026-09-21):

// AccelRanger

#include "MuxSensor.h"
#include <Wire.h>
#include <VL53L1X.h>

// ToF config
VL53L1X tof;
#define OBSTACLE_MM          135
#define TOF_INTERVAL_MS       15   // match the timing budget (50 000 µs = 50 ms)
#define OBSTACLE_CONFIRM       1

bool     tofOk           = false;
uint16_t tofDistance     = 9999;
uint32_t tofLastRead     = 0;
uint8_t  obstacleCounter = 0;

// line sensor pins
#define PIN_S0   12
#define PIN_S1   11
#define PIN_S2   10
#define PIN_S3    8
#define PIN_COM  A0

#define STOP_BT 7

#define AVOID_TURN_SPEED 100

MuxSensor sensor(PIN_S0, PIN_S1, PIN_S2, PIN_S3, PIN_COM, POLARITY_DARK_LOW);
uint8_t digital[MUX_NUM_CHANNELS];

// motor pins
#define LEFT_A    6
#define LEFT_B    9
#define RIGHT_A   5
#define RIGHT_B   3

// PID config
int   baseSpeed          = 160;
float kp                 = 0.07f;
float ki                 = 0.0005f;
float kd                 = 2.8f;
int   sharpTurnThreshold = 40;
int   minTurnSpeed       = 80;
float iClamp             = 800.0f;

int leftLost = 130;
int rightLost = 255;

int avoidedCNT = 0;

// PID state
int   last_error = 0;
float integral   = 0.0f;

// ── Motor helpers ─────────────────────────────────────
void setMotors(int left, int right) {
  left  = constrain(left,  -255, 255);
  right = constrain(right, -255, 255);
  analogWrite(LEFT_A,  left  > 0 ?  left  : 0);
  analogWrite(LEFT_B,  left  < 0 ? -left  : 0);
  analogWrite(RIGHT_A, right > 0 ?  right : 0);
  analogWrite(RIGHT_B, right < 0 ? -right : 0);
}
void stop() { setMotors(0, 0); }

// ── ToF: returns true on a fresh valid reading ────────
bool updateToF() {
  if (!tofOk) return false;
  if (millis() - tofLastRead < TOF_INTERVAL_MS) return false;
  if (!tof.dataReady()) return false;

  tof.read(false);
  tofLastRead = millis();

  if (tof.ranging_data.range_status == VL53L1X::RangeValid && tof.ranging_data.range_mm > 5) {
    tofDistance = tof.ranging_data.range_mm;
    //Serial.print("distance TOF: ");
    //Serial.println(tofDistance);
    return true;   // ← caller knows a real reading just landed
  }
  return false;
}

// ── Obstacle detection: only call with a fresh reading ──
bool obstacleDetected(bool freshReading) {
  if (!freshReading) return false;

  if (tofDistance < OBSTACLE_MM) {
    obstacleCounter++;
    Serial.print("Obstacle counter: ");
    Serial.print(obstacleCounter);
    Serial.print("  dist=");
    Serial.println(tofDistance);
  } else {
    obstacleCounter = 0;
  }

  return obstacleCounter >= OBSTACLE_CONFIRM;
}

// ── Line present? (any sensor active) ────────────────
bool lineVisible() {
  sensor.getDigital(digital);
  for (uint8_t i = 0; i < MUX_NUM_CHANNELS; i++) {
    if (digital[i]) return true;
  }
  return false;
}

// ── Weighted position ─────────────────────────────────
int readPosition() {
  sensor.getDigital(digital);
  long weightedSum = 0;
  int  activeCount = 0;
  for (uint8_t i = 0; i < MUX_NUM_CHANNELS; i++) {
    if (digital[i]) {
      weightedSum += (long)i * 1000;
      activeCount++;
    }
  }
  if (activeCount == 0) return -1;
  return (int)(weightedSum / activeCount);
}

// ── Adaptive speed ────────────────────────────────────
int getAdaptiveSpeed(int error) {
  int absError = abs(error);
  if (absError <= sharpTurnThreshold) return baseSpeed;
  float t = (float)(absError - sharpTurnThreshold) / (7500 - sharpTurnThreshold);
  t = constrain(t, 0.0f, 1.0f);
  return (int)(baseSpeed - (baseSpeed - minTurnSpeed) * t);
}

void avoidObstacle() {
  Serial.println("new");
  delay(150);
  setMotors(255, -255); // turn right
  delay(150);
  setMotors(0,0);
  delay(250);
  setMotors(255,255);
  delay(500);
  setMotors(0,0);
  delay(250);
  setMotors(-255,255);
  delay(225);
  setMotors(0,0);
  delay(100);
  setMotors(255,255);
  delay(400);
  setMotors(0,0);

  Serial.println("Scanning for line...");
  uint32_t scanStart = millis();
  bool found = false;
  while (millis() - scanStart < 500) {
    if (lineVisible()) {
      found = true;
      break;
    }
    setMotors(AVOID_TURN_SPEED, AVOID_TURN_SPEED / 2);
    delay(20);
  }

  if (!found) {
    Serial.println("Line not found, spinning...");
    scanStart = millis();
    while (millis() - scanStart < 500) {
      setMotors(AVOID_TURN_SPEED, -AVOID_TURN_SPEED);
      delay(20);
      if (lineVisible()) break;
    }
  }

  stop();
  delay(50);

  // Reset PID state so there's no kick from stale error
  last_error     = 0;
  integral       = 0.0f;
  obstacleCounter = 0;

  tof.stopContinuous();
  delay(5);  // brief settle
  tof.startContinuous(TOF_INTERVAL_MS);
  Serial.println("Avoidance done, resuming line follow.");
}

// ── PID step ──────────────────────────────────────────
void pidStep() {

  int position = readPosition();
  if (position < 0) {
    setMotors(leftLost, rightLost);
    return;
 }

  int error = position - 7500;

  if (abs(error) < abs(last_error)) {
    integral *= 0.85f;
  }

  integral += error;
  integral  = constrain(integral, -iClamp, iClamp);

  int correction = (int)(kp * error)
                 + (int)(ki * integral)
                 + (int)(kd * (error - last_error));

  int speed = getAdaptiveSpeed(error);
  setMotors(speed + correction, speed - correction);
  last_error = error;
}

// ── Setup ─────────────────────────────────────────────
void setup() {
  Serial.begin(9600);

  pinMode(LEFT_A,      OUTPUT);
  pinMode(LEFT_B,      OUTPUT);
  pinMode(RIGHT_A,     OUTPUT);
  pinMode(RIGHT_B,     OUTPUT);
  pinMode(LED_BUILTIN, OUTPUT);
  pinMode(STOP_BT,     INPUT_PULLUP);

  Wire.begin();
  Wire.setClock(400000);

  tof.setTimeout(500);
  if (tof.init()) {
    tof.setDistanceMode(VL53L1X::Short);
    tof.setMeasurementTimingBudget(50000);
    tof.startContinuous(TOF_INTERVAL_MS);
    tofOk = true;
    Serial.println("VL53L1X OK");
  } else {
    Serial.println("VL53L1X not found!");
  }

  sensor.begin();
  stop();

  Serial.println("Calibrating...");
  digitalWrite(LED_BUILTIN, HIGH);
  bool ok = sensor.calibrate(12000UL);
  digitalWrite(LED_BUILTIN, LOW);
  Serial.println(ok ? "Calibration OK" : "Calibration low-contrast!");

  delay(1000);
}

// loop
void loop() {
  bool fresh = updateToF();
  
  if (digitalRead(STOP_BT) == LOW) {
    stop();
    Serial.print("pressed");
    while (true);
  }

  if (obstacleDetected(fresh)) {
    stop();
    avoidObstacle();
  } else {
    pidStep();
  }
}

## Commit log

2026-05-05 Remove getting started, PCB, and 3D printing sections
    Removed getting started section, PCB details, and 3D printing information from README.
2026-05-05 repo organization
    [ASFALT_LINE_FOLLOWER_MOTOR_MOUNT.stl, ASFALT_LINE_FOLLOWER_MOTOR_MOUNT_V0.f3d, ASLNF_MOTOR_HOLDER_MAIN.stl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]
2026-05-15 model insertion
    [LINE_SENSOR_TRCT.stl]
2026-06-02 added integral clamp > PD >> PID
2026-06-04 added multiple checks for tof for obstacle avoidance and raised I2C speed
    [ASFALT_LNF.ino]
2026-06-04 fixed obstacle avoidance
    added timeouts for obstacle avoidance now just configuring
    [ASFALT_LNF.ino]
2026-06-04 fixed duped code in mux header lib
    [ASFALT_LNF.ino, tofDiag.cpp]
2026-06-05 added state machine for avoidance and added millis for avoidance and TOF
    [ASFALT_LNF.ino]
2026-06-06 updated regulators and avoidance and overall made it comptition ready
    t
    [ASFALT_LNF.ino]
2026-09-12 v3 motor holder
    [ASLNF_MOTOR_HOLDER_MAIN.stl, ASLNF_MOTOR_HOLDER_TOP.stl]
2026-09-13 added new version
    [LINE_SENSOR_TRCT.stl]
2026-09-15 added i2c diagnostic
2026-09-25 added more tracks that the robot was calibrated with
